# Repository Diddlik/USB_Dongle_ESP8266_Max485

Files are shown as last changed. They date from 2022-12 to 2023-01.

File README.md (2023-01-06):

# USB_Dongle_ESP8266_Max485

There is a USB dongle with the Max485 Modbus controller for the inverter Growatt

The main idea was to find a solution for Growatt inverter to read the values. The simple solution is almost always the best solution, this has determined my way.

Growatt has a USB interface which is intended for the USB dongle Shine. In itself, the original solution is almost unusable, because very slow response times, often no connection to the cloud. The desire was to have everything locally and almost in real time to read the values. 

This dongle is plugged into the USB socket of Growatt and the outputs of ModBus 3 and 4 are connected to the connectors on the dongle A and B.
When Growatt produces the current, it also supplies the dongle and sends the corresponding values

The main part is solved by ESPHome. The configuration file is included in the repository. Quite commonly flash Wemos D1 Mini with ESPHome, customize the config for yourself. 

Dallas Sensor ist optionaly. If you don't want to use it, you schould not solder a R1. 

# Images

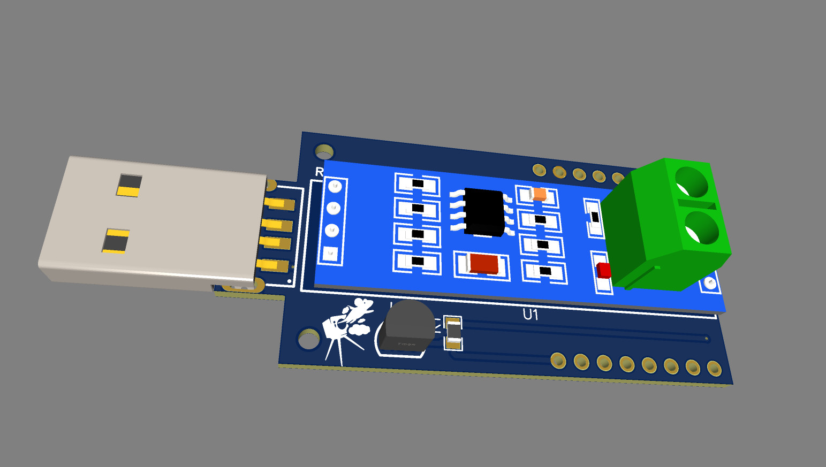
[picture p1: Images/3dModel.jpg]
3dModel

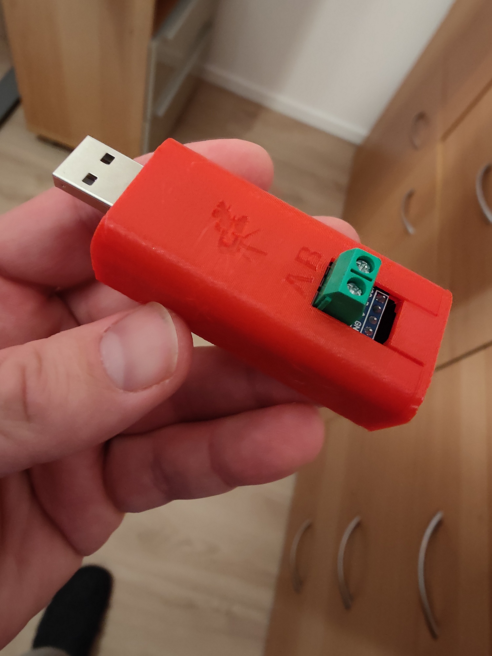
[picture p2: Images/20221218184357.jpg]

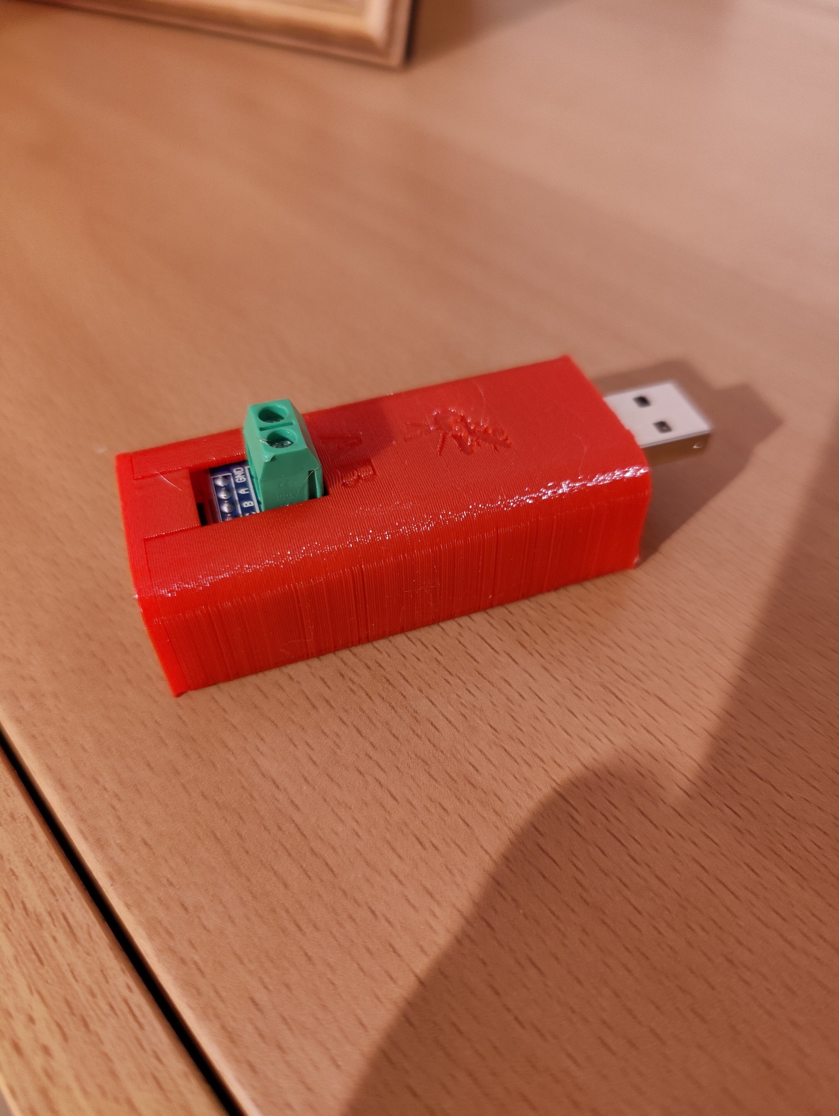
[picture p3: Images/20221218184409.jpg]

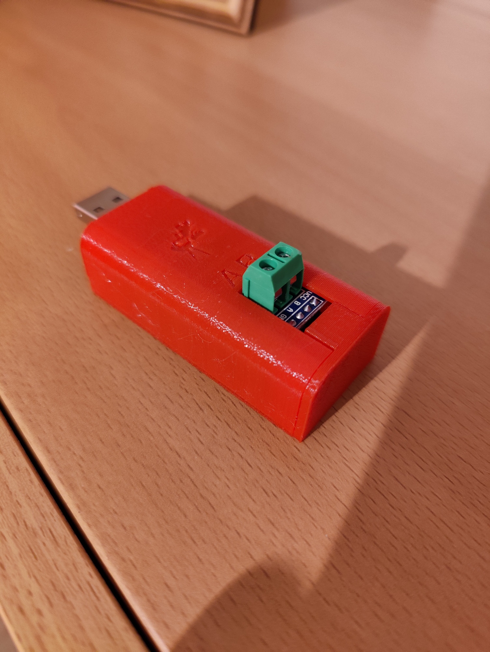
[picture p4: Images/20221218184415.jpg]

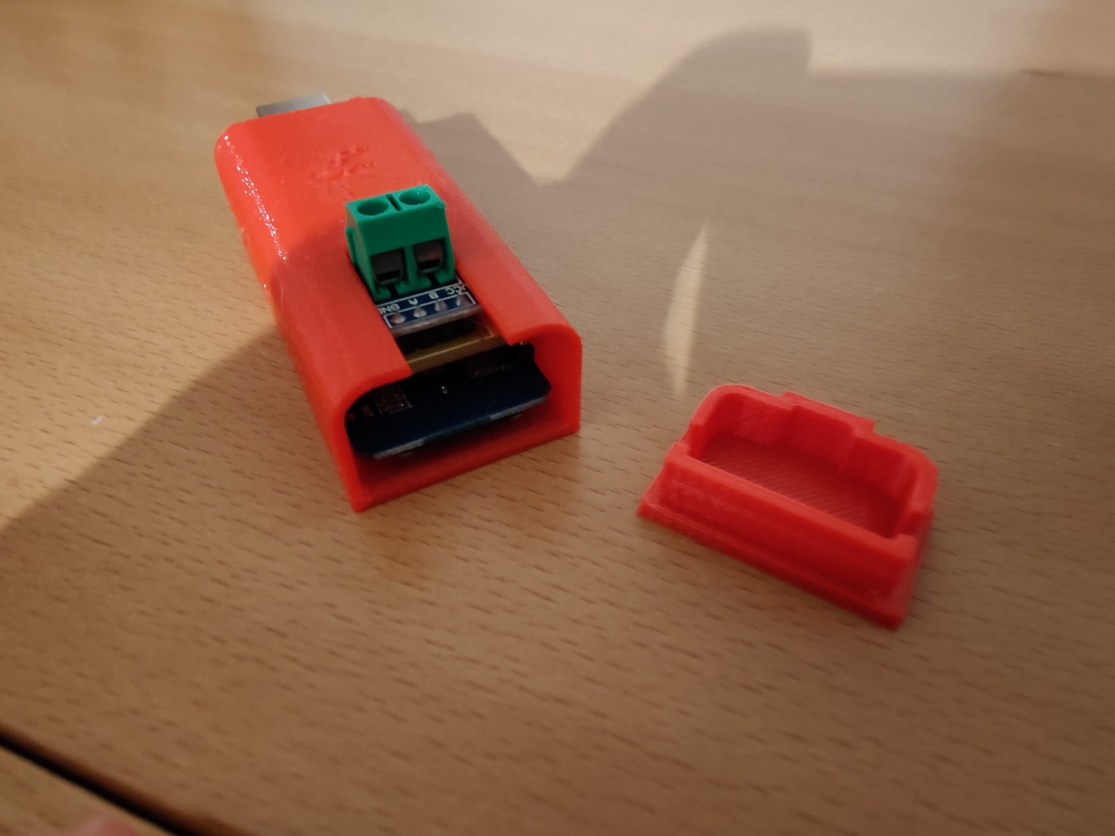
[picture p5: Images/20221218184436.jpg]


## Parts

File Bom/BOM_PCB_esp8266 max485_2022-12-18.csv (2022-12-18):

ID | Name | Designator | Footprint | Quantity | Manufacturer Part | Manufacturer | Supplier | Supplier Part | Price
1 | WEMOS_D1_MINI | U4 | DIP-16_WEMOS_D1_MINI_PRO4 | 1 | Wemos_D1_mini_Pro4 | null | LCSC | C2837266
2 | USB-A | USB1 | USB-A-SMD_U217-041N-4BV81 | 1 | U217-04XN-XXR84 | XKB Enterprise | LCSC | C319178 | 0.009
3 | 4.7k | R1 | R0805 | 1
4 | DS18B20 | U2 | TO-92-3_L4.9-W3.7-P1.27-L | 1 | DS18B20 | UMW(友台半导体) | LCSC | C376006 | 0.122
5 | UART RS485 Converter HW-97 | U1 | HW-97 | 1

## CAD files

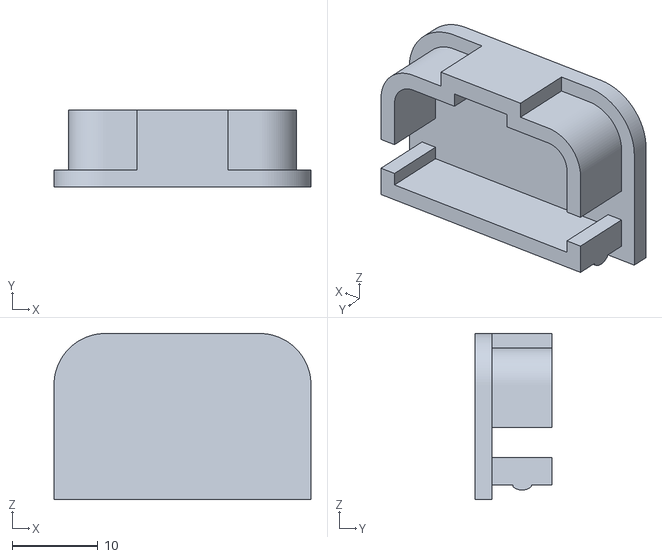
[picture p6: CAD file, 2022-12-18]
STL/top.stl
30.0 x 9.00 x 19.4

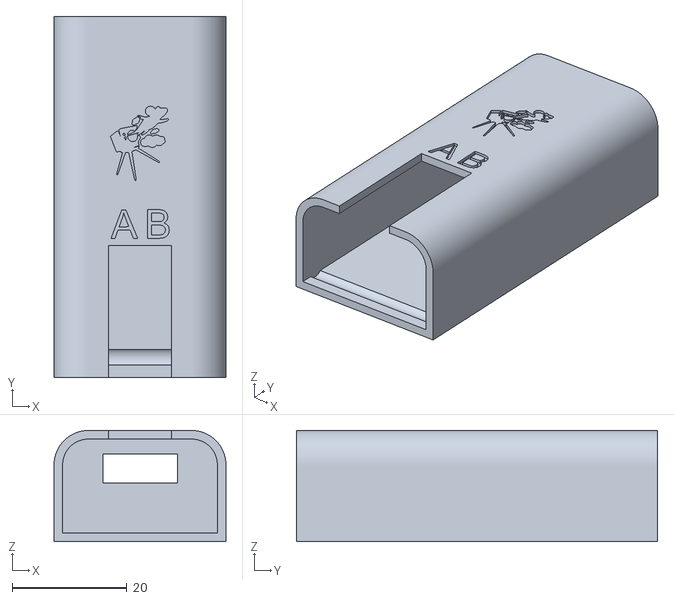
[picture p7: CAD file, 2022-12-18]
STL/body.stl
30.0 x 63.0 x 19.4

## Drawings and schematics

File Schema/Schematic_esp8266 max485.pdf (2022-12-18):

# GNDGND

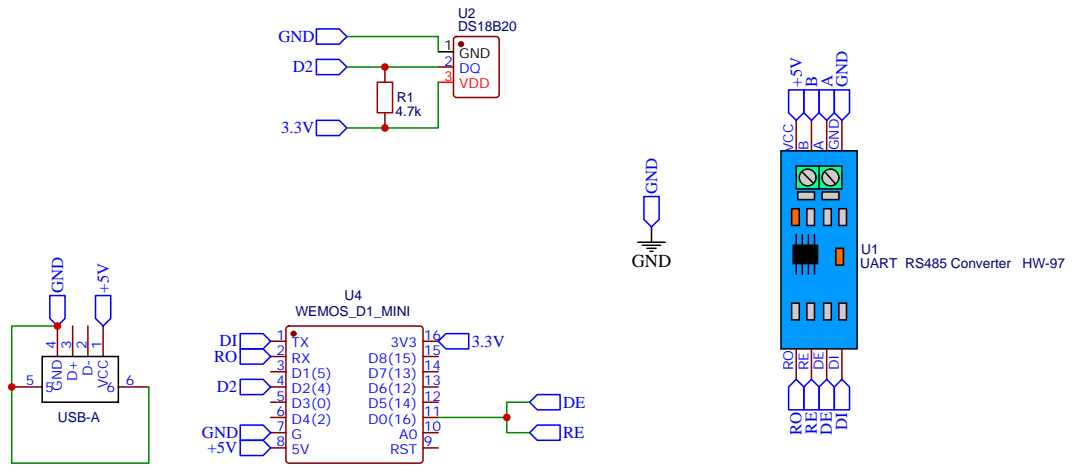
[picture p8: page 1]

Drawn By: Pavel Eremeev

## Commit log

2022-12-18 rev 2: Growatt dongle stick
    [BOM_PCB_esp8266 max485_2022-12-18.csv, body.stl, top.stl]
2022-12-20 Update growatt-west.yaml
    added sensor customization for better recognition in Ha
2023-01-05 UART output
    UART debug output set to UART1.
    Dallas adress-description changed
